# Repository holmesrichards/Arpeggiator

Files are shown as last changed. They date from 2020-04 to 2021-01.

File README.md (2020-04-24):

# ArpeggiatorModule
Code and hardware for Kosmo/Eurorack arpeggiator module

This is an arpeggiator based on a variant of the [dacarduino](https://github.com/holmesrichards/dacarduino) board. As such it uses the dacarduino library as well as the Arpeggiator library in this repository.

Design is for Kosmo format module but the PCB and code would work equally well for a Eurorack version. It would just need a smaller front panel. Shorter anyway, maybe wider.

THIS IS A WORK IN PROGRESS.

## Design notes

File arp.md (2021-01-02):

# dacarduino arpeggiator:

What really distinguishes an arpeggiator from a sequencer?

At its most basic, with a sequencer you specify an ordered set of notes and it plays them in that order. With a quantizer you specify an unordered set of notes and it plays them in some order.

(The Arturia KeyStep's arpeggiator's "order" mode breaks that distinction by playing the notes in the order entered. There is little to distinguish that mode from a basic Baby-n sequencer. One can imagine extending sequencer and arpeggiator capabilities toward one another until there's no difference between one and the other, but let's not.)

So an arpeggiator needs:
- A way to specify (unordered) notes (or control voltages more generally)
- A way to specify ordering

You can use the LMNC sequencer with my modifications to do some of that, but it requires you to enter each note as a knob setting. A distinguishing feature of an arpeggiator should be to allow you to more easily and quickly specify the notes to use. For instance the KeyStep arpeggiator just takes all the notes held down on the keyboard simultaneously. That would be problematic with a non MIDI module — unless it had a mini keyboard on the front panel. 

Some arps on the market:

**2HP Arp http://www.twohp.com/modules/arp**
uses knobs (apparently potentiometers) + CV to select chord and mode (ordering). Chords are: Major, Major 7, Dominant 7, Minor, Minor 7, Diminished, Half Diminished 7, Full Diminished 7, Augmented, Augmented 7, Sus 4, Sus 4 Maj 7, Sus 4 Min 7. Modes are: Ascending one octave, Ascending two octaves, Descending one octave, Descending two octaves, Pendulum one octave, Pendulum two octaves, Random one octave, Random two octaves

**Flame Arpeggiator 2013**
**Flame Chord Machine II **
has on-panel push button keyboard, CV for arp functions. 2013 has 2x16 display and a knob apparently.

**Barton CV Arpeggiator**
knobs/CV control range (1 to 5 octaves), mode (Up/Down (exclusive?), Up Repeating, Down Repeating, Pendulum (inclusive?), Up and stay, Down and stay, Random), and chord (basically you can get any combination of root, 3rd (major/minor/no), 5th (perfect/no), 7th (major, minor, no) (so no augmented or diminished...)).

**KeyStep**
modes are Up, Down, Inclusive, Exclusive, Random, Order, Up x2, Down x2

How about this?

##Inputs:

- CV: input for root. Press a keyboard key and change chord root. (KeyStep can't do this! Though maybe can achieve it using 2nd MIDI keyboard...)
- Clock

##Controls:

- 12 push buttons + rotary switch to select notes, order, and range (requires mux/demux) - e.g. in note mode push buttons 1-12 toggle notes, in chord mode they select chord, in order mode they select order, in range mode they select range, rotary switch selects mode. Adjacent LEDs show setting.

 | Button | Chord | Order   | Range   |
 |--------|-------|---------|---------|
 | C      |  M    |  up     | Oct     |
 | C#     |  m    |  down   | Oct+1   |
 | D      |  7    |  inc    | Oct+5   |
 | Eb     |  M7   |  exc    | 2 Oct   |
 | E      |  m7   |  up/dn  | 2 Oct+1 |
 | F      |  dim  |  dn/up  | 2 Oct+5 |
 | F#     |  dim7 |  up x2  | 3 Oct   |
 | G      |  aug  |  dn x2  | 3 Oct+1 |
 | G#     |  sus2 |  inc x2 | 4 Oct   |
 | A      |  sus4 |  exc x2 | 4 Oct+1 |
 | Bb     |  8va  |  up x3  | 5 Oct   |
 | B      |  5    |  dn x3  | 5 Oct+1 |
 
 - 1 push button for stretch mode. When enabled, if the selected number of notes, order, and range yields a pattern whose length isn't a power of 2 (such as 4, 8, or 16) then the pattern is stretched to such a length by repeating the last several notes. For example, a five-note pattern in up order with Oct range yields a pattern of length 5 with stretch mode off: 1-2-3-4-5. With stretch mode on this is extended to length 8 by repeating the last three notes: 1-2-3-4-5-3-4-5. Adjacent LEDs show setting.
 
 - 2 push buttons for start/stop and reset

Originally this was going to just use the dacarduino board, but the current design needs fewer gates and CVs than it provides but needs a pair of shift registers to handle the LEDs. Tempting though it is to try to stuff the shift registers into the dacarduino design, they probably would not be used often enough to justify it. So the arpeggiator uses its own board, based on but different from dacarduino.

##Outputs:

- CV
- Note (gate)
- Start (gate)

Arduino pin needs:

Analog in:

- CV In (protected)
- Buttons and rotary switch (unprotected; wire as resistor ladder)

Analog out:

- CV Out

Digital in:

- Clock (protected)

Digital out:

- Note (protected)
- Start (protected)
- 3 pins for LED shift registers

Total 3 analog pins, 6 digital

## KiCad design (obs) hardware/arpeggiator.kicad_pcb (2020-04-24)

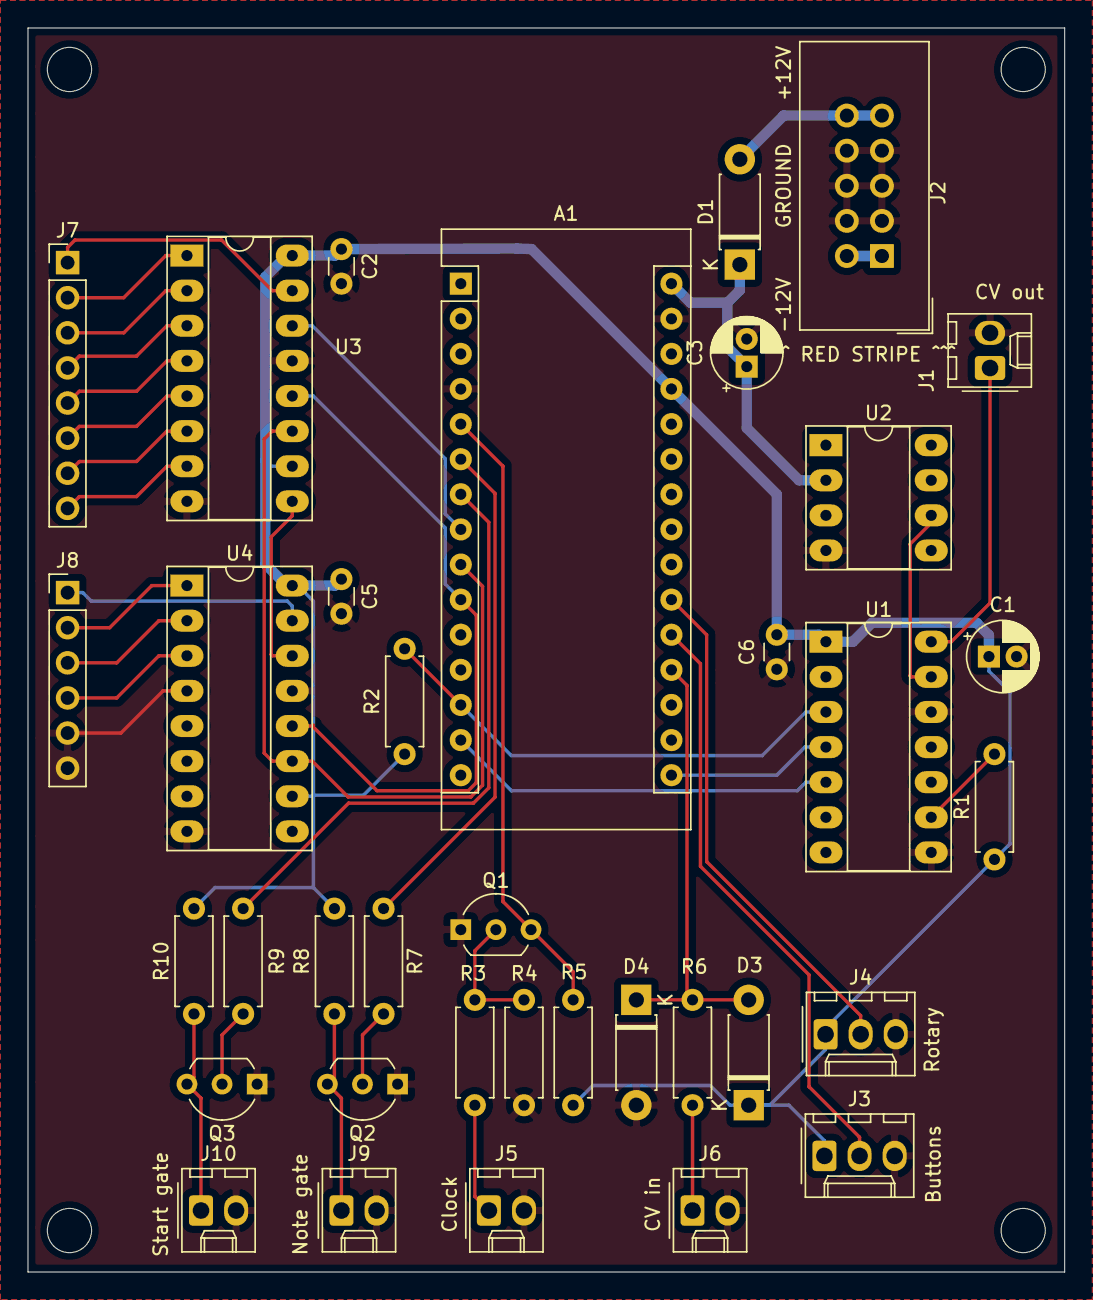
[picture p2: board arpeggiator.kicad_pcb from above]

Board: 2 copper layers, 75.0 x 90.0 mm, 40 parts (0 on the bottom side), 41 nets.

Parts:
A1: Arduino_Nano_v3.x 5V; Arduino_Nano
C1, C3: 10uF; CP_Radial_D5.0mm_P2.00mm
C2, C5, C6: 0.1uF; C_Disc_D3.0mm_W1.6mm_P2.50mm
D1, D3, D4: 1N5817; D_DO-41_SOD81_P7.62mm_Horizontal
H1, H2, H3, H4: MountingHole; MountingHole_3.2mm_M3
J1: CV_OUT; Molex_KK-254_AE-6410-02A_1x02_P2.54mm_Vertical
J2: EURO_PWR_2x5; IDC-Header_2x05_P2.54mm_Vertical
J3: BUTTONS; Molex_KK-254_AE-6410-03A_1x03_P2.54mm_Vertical
J4: ROTARY; Molex_KK-254_AE-6410-03A_1x03_P2.54mm_Vertical
J5: GATE IN; Molex_KK-254_AE-6410-02A_1x02_P2.54mm_Vertical
J6: CV IN; Molex_KK-254_AE-6410-02A_1x02_P2.54mm_Vertical
J7: Conn_01x08; PinHeader_1x08_P2.54mm_Vertical
J8: Conn_01x06; PinHeader_1x06_P2.54mm_Vertical
J9: Note gate; Molex_KK-254_AE-6410-02A_1x02_P2.54mm_Vertical
J10: Start gate; Molex_KK-254_AE-6410-02A_1x02_P2.54mm_Vertical
Q1, Q2, Q3: 2N3904; TO-92_Inline_Wide
R1, R2: 10K; R_Axial_DIN0207_L6.3mm_D2.5mm_P7.62mm_Horizontal
R3: 100k; R_Axial_DIN0207_L6.3mm_D2.5mm_P7.62mm_Horizontal
R4: 1M; R_Axial_DIN0207_L6.3mm_D2.5mm_P7.62mm_Horizontal
R5: 10k; R_Axial_DIN0207_L6.3mm_D2.5mm_P7.62mm_Horizontal
R6, R7, R8, R9, R10: 1k; R_Axial_DIN0207_L6.3mm_D2.5mm_P7.62mm_Horizontal
U1: MCP4922; DIP-14_W7.62mm_Socket_LongPads
U2: REF02CP+; DIP-8_W7.62mm_Socket_LongPads
U3, U4: 74HC595; DIP-16_W7.62mm_Socket_LongPads

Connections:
+VIN: A1.30, C3.1, D1.1, U2.2
/Arduino/A0: A1.19, D3.2, D4.1, R6.1
/Arduino/A1: A1.20, J3.2
/Arduino/A2: A1.21, J4.2
/Arduino/D2: A1.5, Q1.3, R5.1
/Arduino/D3: A1.6, R7.2
/Arduino/D4: A1.7, R9.2
/Arduino/D5: A1.8, U3.14
/Arduino/D6: A1.9, U3.11, U4.11
/Arduino/D7: A1.10, U3.12, U4.12
/Arduino/DAC_CS: A1.13, R2.2, U1.3
/Arduino/MOSI: A1.14, U1.5
/Arduino/SCK: A1.16, U1.4
/DAC/CV_OUT: J1.1, U1.14
/Digital out/NOTE_GATE: J9.1, Q2.3, R8.1
/Digital out/START_GATE: J10.1, Q3.3, R10.1
/Inputs/CV in/CV_IN: J6.1, R6.2
/Inputs/Clock in/GATE_IN: J5.1, R3.2
/Voltage reference/VREF: U1.13, U2.6
GND: A1.4, A1.29, C1.2, C2.2, C3.2, C5.2, C6.2, D4.2, J1.2, J2.3, J2.4, J2.5, J2.6, J2.7, J2.8, J3.3, J4.3, J5.2, J6.2, J8.6, J9.2, J10.2, Q1.1, Q2.1, Q3.1, R4.1, U1.8, U1.12, U2.4, U3.8, U3.13, U4.8, U4.13
unnamed: D1.2, J2.9, J2.10
unnamed: J2.1, J2.2
unnamed: J7.1, U3.15
unnamed: J7.2, U3.1
unnamed: J7.3, U3.2
unnamed: J7.4, U3.3
unnamed: J7.5, U3.4
unnamed: J7.6, U3.5
unnamed: J7.7, U3.6
unnamed: J7.8, U3.7
unnamed: J8.1, U4.15
unnamed: J8.2, U4.1
unnamed: J8.3, U4.2
unnamed: J8.4, U4.3
unnamed: J8.5, U4.4
unnamed: Q1.2, R3.1, R4.2
unnamed: Q2.2, R7.1
unnamed: Q3.2, R9.1
unnamed: R1.2, U1.9
unnamed: U3.9, U4.14
VCC: A1.27, C1.1, C2.1, C5.1, C6.1, D3.1, J3.1, J4.1, R1.1, R2.1, R5.2, R8.2, R10.2, U1.1, U3.10, U3.16, U4.10, U4.16

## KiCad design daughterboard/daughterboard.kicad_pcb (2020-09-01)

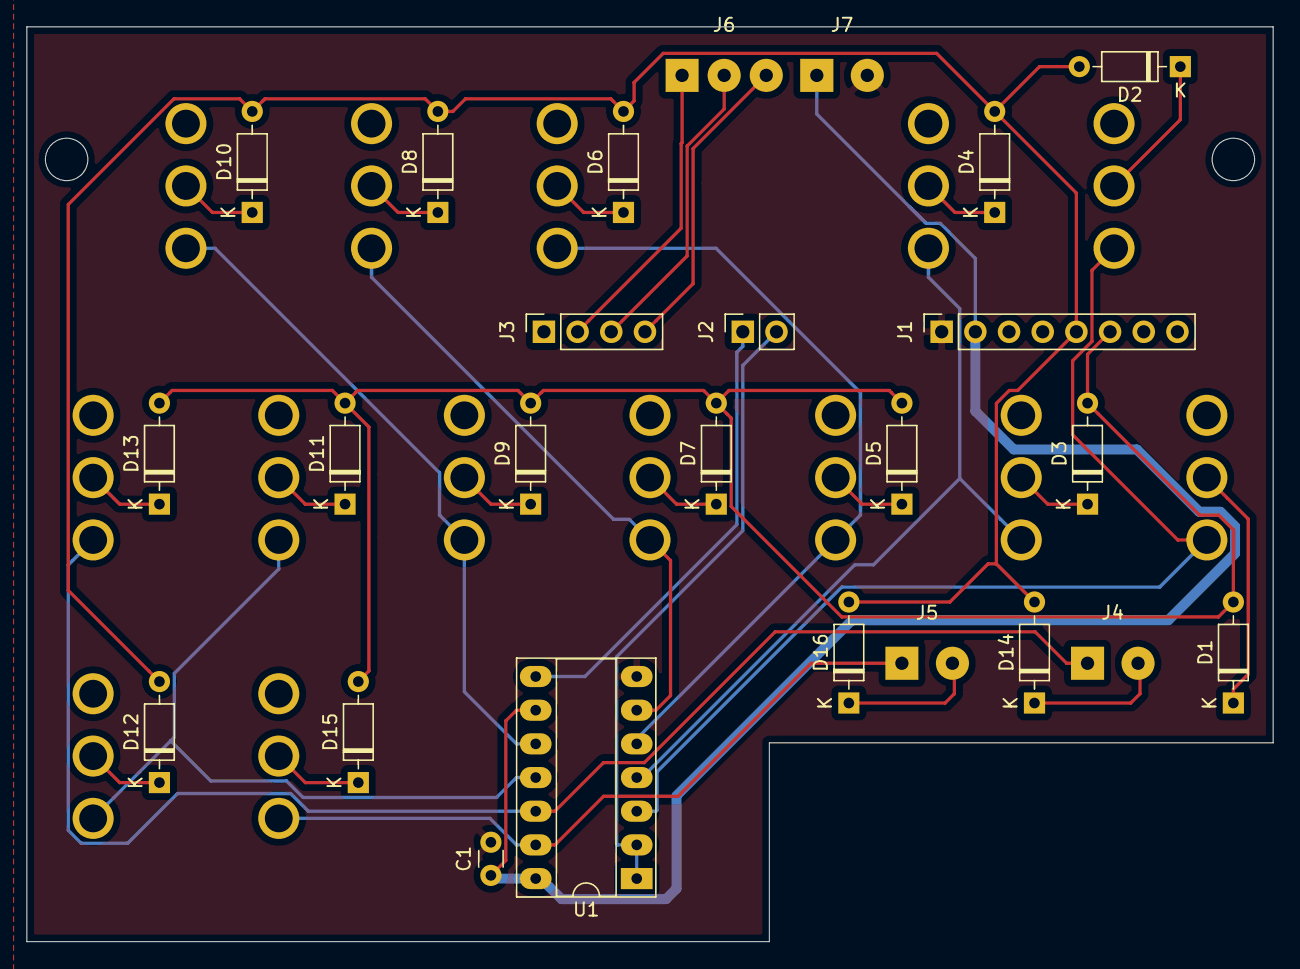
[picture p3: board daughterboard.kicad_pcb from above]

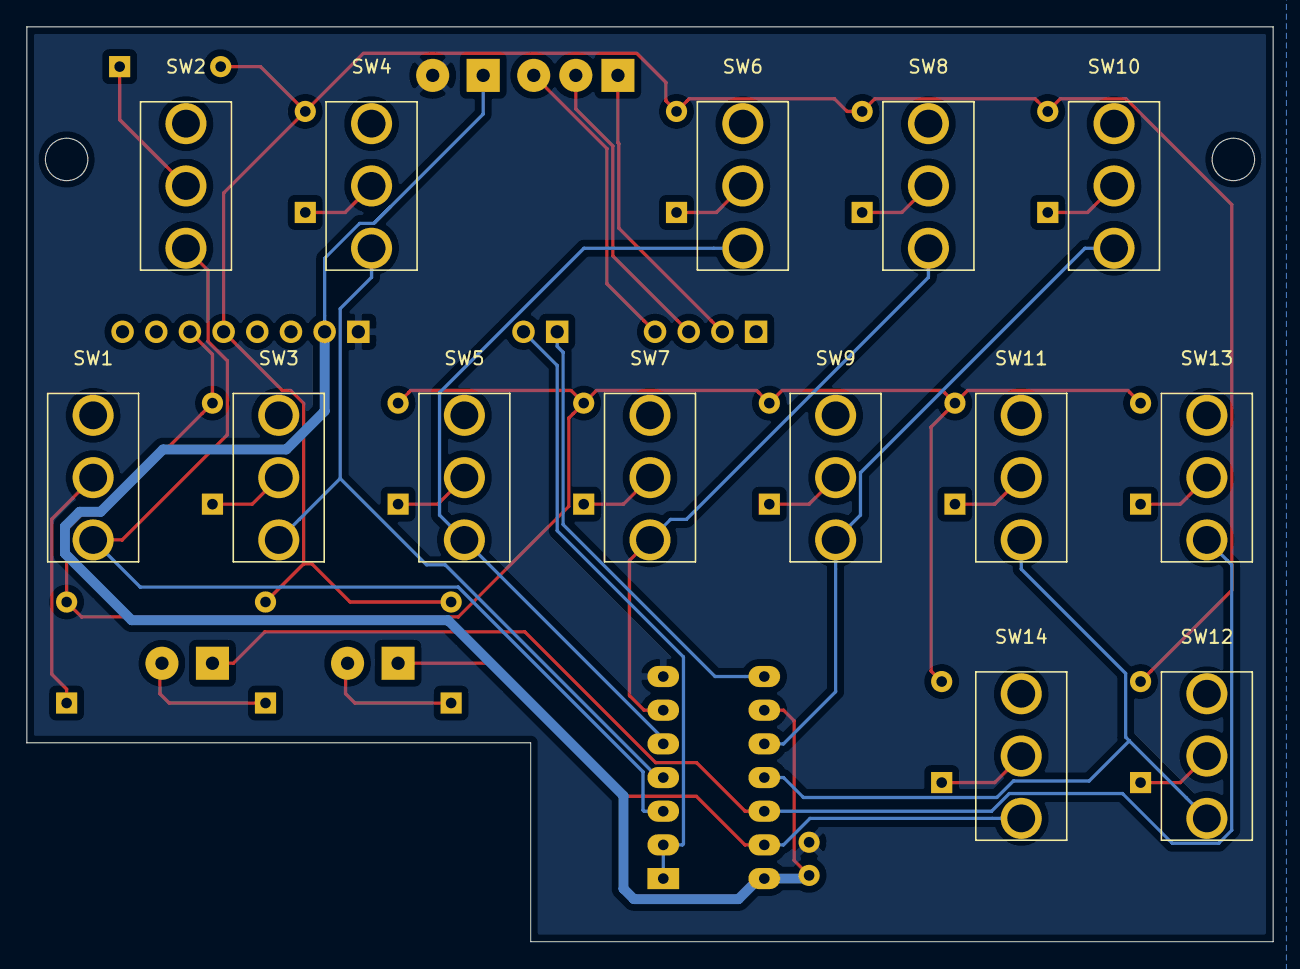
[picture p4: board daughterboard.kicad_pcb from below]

Board: 2 copper layers, 94.0 x 69.0 mm, 41 parts (14 on the bottom side), 33 nets.

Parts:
C1: 100nF; C_Disc_D3.0mm_W1.6mm_P2.50mm
D1, D2, D3, D4, D5, D6, D7, D8, D9, D10, D11, D12, D13, D14, D15, D16: 1N4148; D_DO-35_SOD27_P7.62mm_Horizontal
H1, H2: MountingHole; MountingHole_3.2mm_M3
J1: Conn_01x08; PinSocket_1x08_P2.54mm_Vertical
J2: Conn_01x02; PinSocket_1x02_P2.54mm_Vertical
J3: Conn_01x04; PinSocket_1x04_P2.54mm_Vertical
J4, J5, J7: Conn_01x02; SolderWirePad_1x02_P3.81mm_Drill1mm
J6: Conn_01x05; SolderWirePad_1x03_P3.175mm_Drill1mm
SW1, SW2, SW3, SW4, SW5, SW6, SW7, SW8, SW9, SW10, SW11, SW12, SW13, SW14: SW_SPST; SPDT-toggle-switch-1M-series
U1: 74HC164; DIP-14_W7.62mm_Socket_LongPads

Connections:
/A4: J3.4, J6.3
/A5: J3.3, J6.2
/A6: J3.2, J6.1
/D8: J2.1, U1.8
/D9: J2.2, U1.1, U1.2
/GATE_IN_C: D1.2, D3.2, D5.2, D7.2, D9.2, D11.2, D13.2, D15.2, J1.6
/GATE_IN_D: D2.2, D4.2, D6.2, D8.2, D10.2, D12.2, D14.2, D16.2, J1.5
/RS1: J5.1, SW14.1, U1.13
/RS2: D16.1, J5.2
/SS1: J4.1, SW13.1, U1.12
/SS2: D14.1, J4.2
GND: C1.2, J1.1, J7.2, U1.7
unnamed: D1.1, SW1.2
unnamed: D2.1, SW2.2
unnamed: D3.1, SW3.2
unnamed: D4.1, SW4.2
unnamed: D5.1, SW5.2
unnamed: D6.1, SW6.2
unnamed: D7.1, SW7.2
unnamed: D8.1, SW8.2
unnamed: D9.1, SW9.2
unnamed: D10.1, SW10.2
unnamed: D11.1, SW11.2
unnamed: D12.1, SW12.2
unnamed: D13.1, SW13.2
unnamed: D15.1, SW14.2
unnamed: SW1.1, SW2.1, U1.3
unnamed: SW3.1, SW4.1, U1.4
unnamed: SW5.1, SW6.1, U1.5
unnamed: SW7.1, SW8.1, U1.6
unnamed: SW9.1, SW10.1, U1.10
unnamed: SW11.1, SW12.1, U1.11
VCC: C1.1, J1.2, J7.1, U1.9, U1.14

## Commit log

2020-04-24 Initial version
    [Arduino.sch, CV_in.sch, DAC.sch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]
2020-09-01 Lots of updates belatedly committed
    [Arduino.sch, CV_in.sch, DAC.sch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]
